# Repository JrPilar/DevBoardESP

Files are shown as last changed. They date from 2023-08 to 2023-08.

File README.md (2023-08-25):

# DevBoardESP
Dev Board based on ESP32-S3-WROOM2 chip to controll equatorial mount for telescope.  
Project made in KiCad6, for future printing. Board is architectured for future versions of ArduinoEQ, which will include autofocus motor, onboard RTC, GOTO etc.
Board is powered by 12V, has an USB-C port for COM port and programable NeoPixel.

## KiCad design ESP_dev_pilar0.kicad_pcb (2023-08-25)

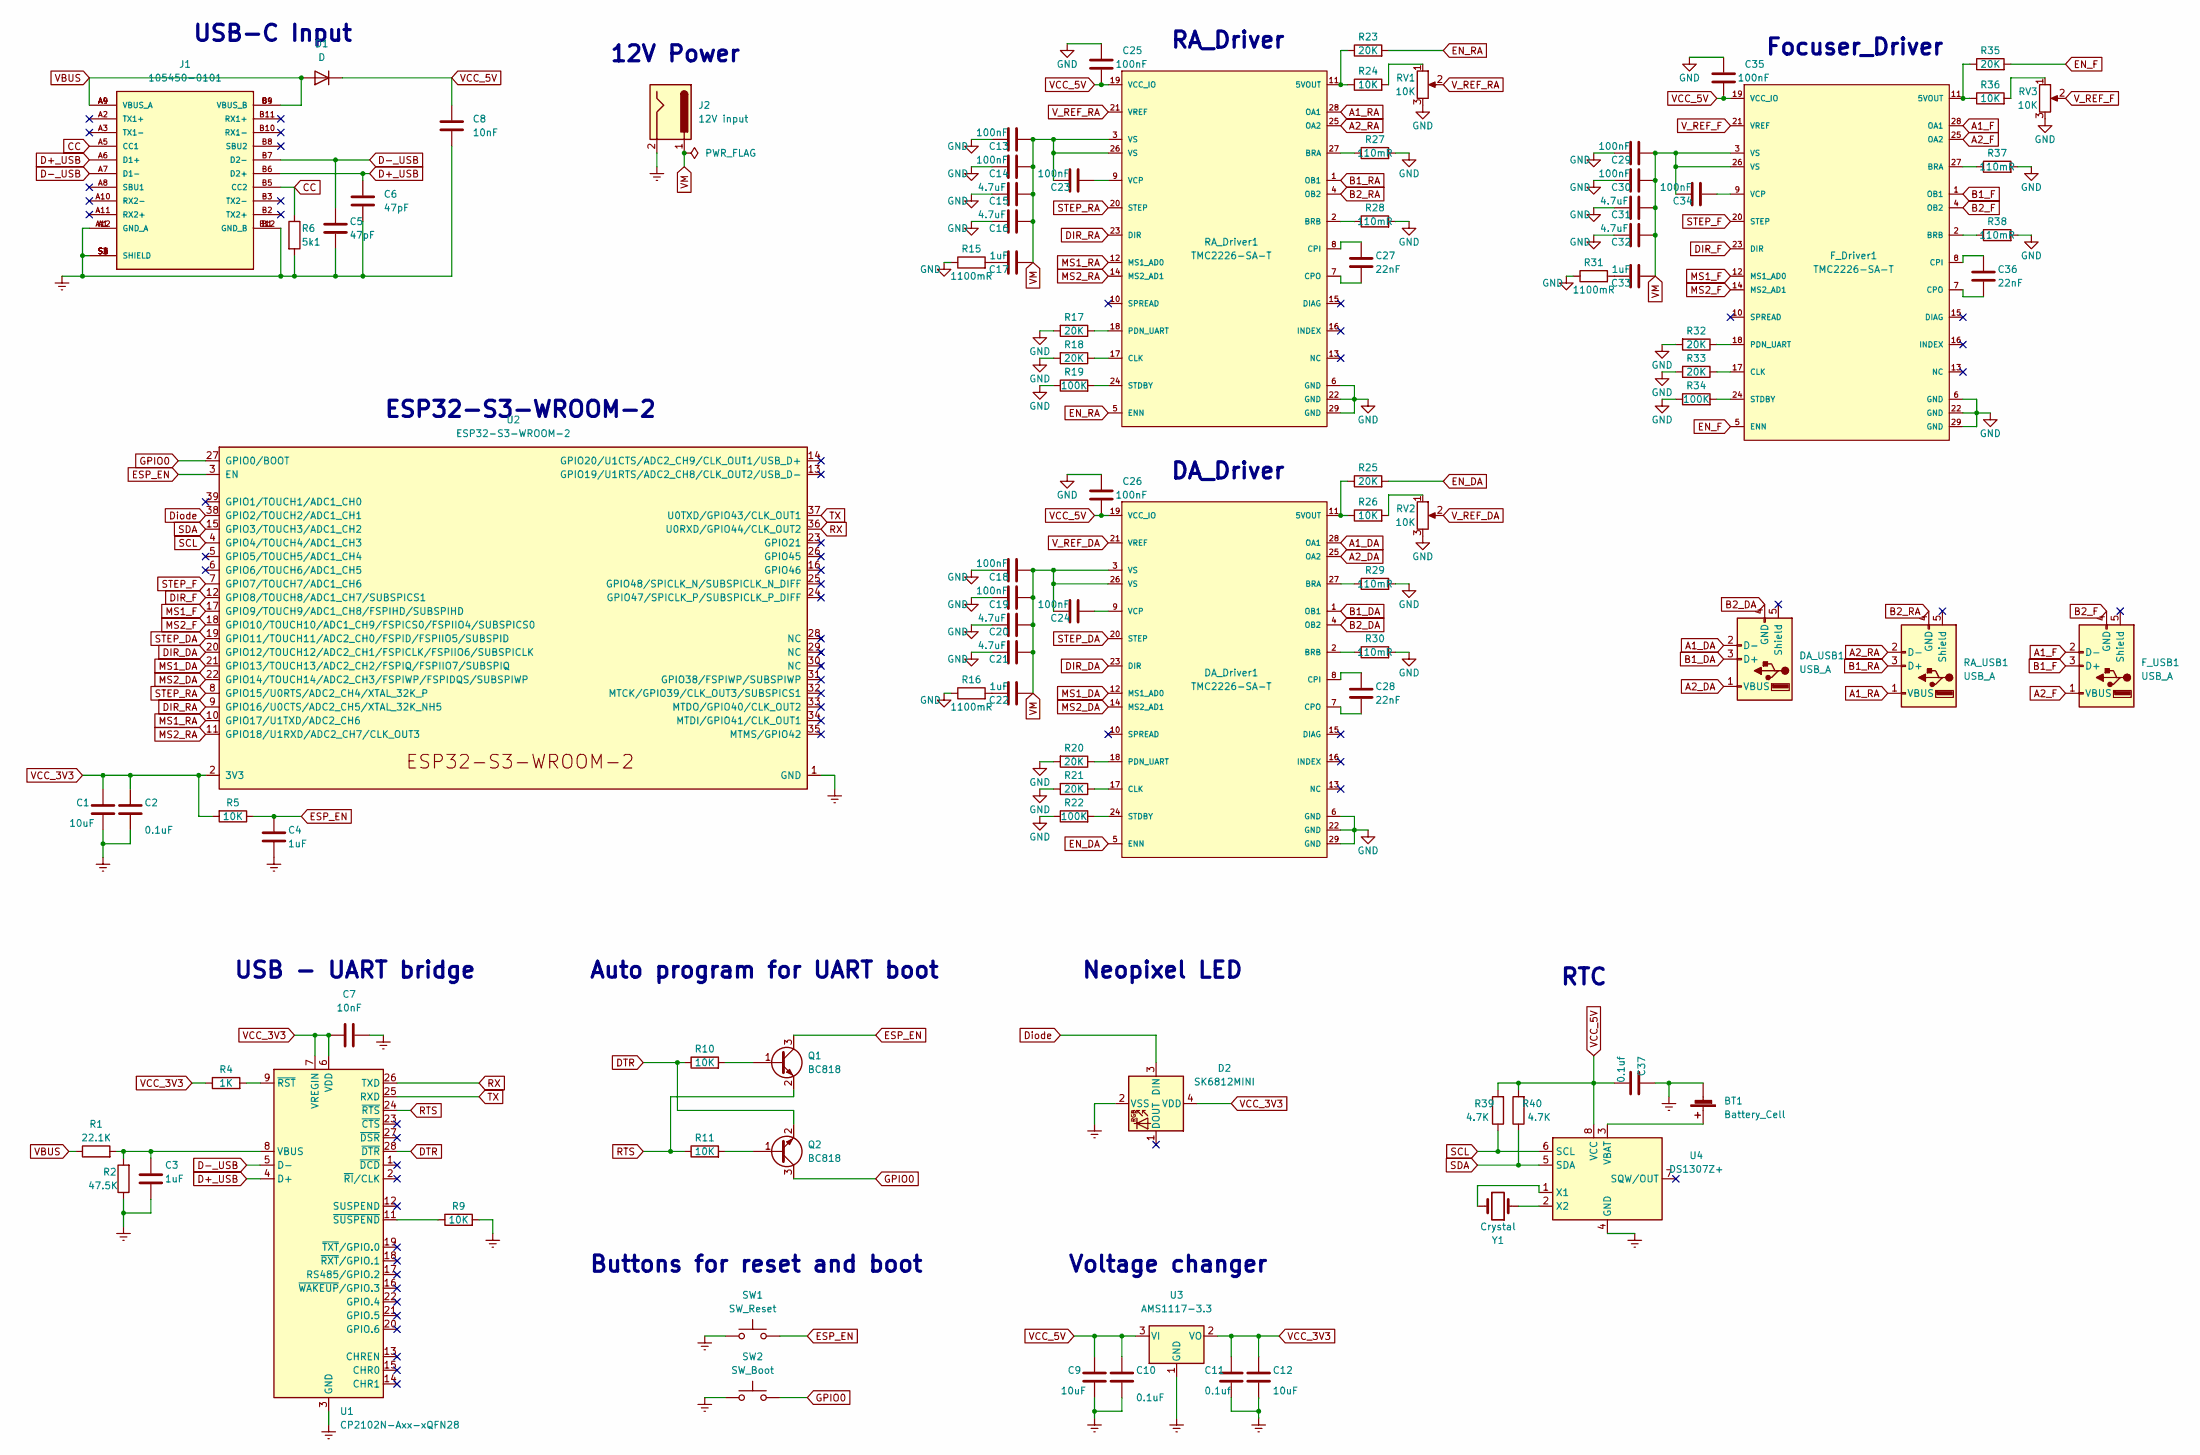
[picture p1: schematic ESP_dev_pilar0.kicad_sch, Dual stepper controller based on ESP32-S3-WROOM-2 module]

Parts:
BT1: Battery_Cell; BatteryHolder_Keystone_1057_1x2032
C1, C9, C12: 10uF; C_1210_3225Metric
C2, C10: 0.1uF; C_0603_1608Metric
C3, C4, C17, C22, C33: 1uF; C_0603_1608Metric
C5, C6: 47pF; C_0603_1608Metric
C7, C8: 10nF; C_0603_1608Metric
C11: 0.1uf; C_0603_1608Metric
C13, C14, C18, C19, C23, C24, C25, C26, C29, C30, C34, C35: 100nF; C_0603_1608Metric
C15, C16, C20, C21, C31, C32: 4.7uF; C_0603_1608Metric
C27, C28, C36: 22nF; C_0603_1608Metric
C37: 0.1uf; C_1210_3225Metric
D1: D; D_SOD-323
D2: SK6812MINI; LED_SK6812MINI_PLCC4_3.5x3.5mm_P1.75mm
DA_Driver1: TMC2226-SA-T; Trinamic-TMC2226-SA-T-IPC_B; mouser part number 700-TMC2226-SA-T; digikey description IC MTR DRV 4.75-29V HTSSOP28
DA_USB1: USB_A; USB_A_Molex_67643_Horizontal
F_Driver1: TMC2226-SA-T; Trinamic-TMC2226-SA-T-IPC_B; mouser part number 700-TMC2226-SA-T; digikey description IC MTR DRV 4.75-29V HTSSOP28
F_USB1: USB_A; USB_A_Molex_67643_Horizontal
J1: 105450-0101; USB_C_Receptacle_Molex_105450-0101; PARTREV A7
J2: 12V input; BarrelJack_Horizontal
Q1, Q2: BC818; SOT-23
R1: 22.1K; R_0603_1608Metric_Pad0.98x0.95mm_HandSolder
R2: 47.5K; R_0603_1608Metric_Pad0.98x0.95mm_HandSolder
R4: 1K; R_0603_1608Metric_Pad0.98x0.95mm_HandSolder
R5, R9, R10, R11: 10K; R_0603_1608Metric_Pad0.98x0.95mm_HandSolder
R6: 5k1; R_0603_1608Metric_Pad0.98x0.95mm_HandSolder
R15, R16, R31: 1100mR; R_1206_3216Metric_Pad1.30x1.75mm_HandSolder
R17, R18, R20, R21, R23, R25, R32, R33, R35: 20K; R_1206_3216Metric_Pad1.30x1.75mm_HandSolder
R19, R22, R34: 100K; R_1206_3216Metric_Pad1.30x1.75mm_HandSolder
R24, R26, R36: 10K; R_1206_3216Metric_Pad1.30x1.75mm_HandSolder
R27, R28, R29, R30, R37, R38: 110mR; R_0805_2012Metric_Pad1.20x1.40mm_HandSolder
R39, R40: 4.7K; R_0603_1608Metric_Pad0.98x0.95mm_HandSolder
RA_Driver1: TMC2226-SA-T; Trinamic-TMC2226-SA-T-IPC_B; mouser part number 700-TMC2226-SA-T; digikey description IC MTR DRV 4.75-29V HTSSOP28
RA_USB1: USB_A; USB_A_Molex_67643_Horizontal
RV1, RV2, RV3: 10K; Potentiometer_Bourns_TC33X_Vertical
SW1: SW_Reset; SW_Push_1P1T_NO_6x6mm_H9.5mm
SW2: SW_Boot; SW_Push_1P1T_NO_6x6mm_H9.5mm
U1: CP2102N-Axx-xQFN28; QFN-28-1EP_5x5mm_P0.5mm_EP3.35x3.35mm
U2: ESP32-S3-WROOM-2
U3: AMS1117-3.3; SOT-223-3_TabPin2
U4: DS1307Z+; SOIC-8_3.9x4.9mm_P1.27mm
Y1: Crystal; Crystal_DS26_D2.0mm_L6.0mm_Vertical

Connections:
A1_DA: DA_Driver1.28 (OA1), DA_USB1.2 (D-)
A1_F: F_Driver1.28 (OA1), F_USB1.2 (D-)
A1_RA: RA_Driver1.28 (OA1), RA_USB1.1 (VBUS)
A2_DA: DA_Driver1.25 (OA2), DA_USB1.1 (VBUS)
A2_F: F_Driver1.25 (OA2), F_USB1.1 (VBUS)
A2_RA: RA_Driver1.25 (OA2), RA_USB1.2 (D-)
B1_DA: DA_Driver1.1 (OB1), DA_USB1.3 (D+)
B1_F: F_Driver1.1 (OB1), F_USB1.3 (D+)
B1_RA: RA_Driver1.1 (OB1), RA_USB1.3 (D+)
B2_DA: DA_Driver1.4 (OB2), DA_USB1.4 (GND)
B2_F: F_Driver1.4 (OB2), F_USB1.4 (GND)
B2_RA: RA_Driver1.4 (OB2), RA_USB1.4 (GND)
CC: J1.A5 (CC1), J1.B5 (CC2), R6.1
D+_USB: C6.1, J1.A6 (D1+), J1.B6 (D2+), U1.4 (D+)
D-_USB: C5.2, J1.A7 (D1-), J1.B7 (D2-), U1.5 (D-)
DIR_DA: DA_Driver1.23 (DIR), U2.20 (GPIO12/TOUCH12/ADC2_CH1/FSPICLK/FSPIIO6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)
DIR_F: F_Driver1.23 (DIR), U2.12 (GPIO8/TOUCH8/ADC1_CH7/SUBSPICS1)
DIR_RA: RA_Driver1.23 (DIR), U2.9 (GPIO16/U0CTS/ADC2_CH5/XTAL_32K_NH5)
DTR: Q2.2 (E), R10.1, U1.28 (~DTR)
Diode: D2.3 (DIN), U2.38 (GPIO2/TOUCH2/ADC1_CH1)
EN_DA: DA_Driver1.5 (ENN), R25.2
EN_F: F_Driver1.5 (ENN), R35.2
EN_RA: R23.2, RA_Driver1.5 (ENN)
ESP_EN: C4.1, Q1.3 (C), R5.1, SW1.2, U2.3 (EN)
Earth: BT1.2 (-), C1.2, C2.2, C3.1, C4.2, C5.1, C6.2, C7.2, C8.2, C9.2, C10.2, C11.2, C12.2, C37.1, D2.2 (VSS), J1.A1 (GND_A), J1.A12 (GND_A), J1.B1 (GND_B), J1.B12 (GND_B), J1.S1 (SHIELD), J1.S2 (SHIELD), J1.S3 (SHIELD), J1.S4 (SHIELD), J2.2, R2.1, R6.2, R9.2, SW1.1, SW2.1, U1.3 (GND), U1.29 (GND), U2.1 (GND), U2.40 (GND), U2.41 (GND), U3.1 (GND), U4.4 (GND)
GND: C13.1, C14.1, C15.1, C16.1, C18.1, C19.1, C20.1, C21.1, C25.1, C26.1, C29.1, C30.1, C31.1, C32.1, C35.1, DA_Driver1.6 (GND), DA_Driver1.22 (GND), DA_Driver1.29 (GND), F_Driver1.6 (GND), F_Driver1.22 (GND), F_Driver1.29 (GND), R15.1, R16.1, R17.2, R18.2, R19.1, R20.2, R21.2, R22.1, R27.2, R28.2, R29.2, R30.2, R31.1, R32.2, R33.2, R34.1, R37.2, R38.2, RA_Driver1.6 (GND), RA_Driver1.22 (GND), RA_Driver1.29 (GND), RV1.3, RV2.3, RV3.3
GPIO0: Q2.3 (C), SW2.2, U2.27 (GPIO0/BOOT)
MS1_DA: DA_Driver1.12 (MS1_AD0), U2.21 (GPIO13/TOUCH13/ADC2_CH2/FSPIQ/FSPIIO7/S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)
MS1_F: F_Driver1.12 (MS1_AD0), U2.17 (GPIO9/TOUCH9/ADC1_CH8/FSPIHD/SUBSPIHD)
MS1_RA: RA_Driver1.12 (MS1_AD0), U2.10 (GPIO17/U1TXD/ADC2_CH6)
MS2_DA: DA_Driver1.14 (MS2_AD1), U2.22 (GPIO14/TOUCH14/ADC2_CH3/FSPIWP/FSPIDQS/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)
MS2_F: F_Driver1.14 (MS2_AD1), U2.18 (GPIO10/TOUCH10/ADC1_CH9/FSPICS0/FSPIIO4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)
MS2_RA: RA_Driver1.14 (MS2_AD1), U2.11 (GPIO18/U1RXD/ADC2_CH7/CLK_OUT3)
unnamed: BT1.1 (+), U4.3 (VBAT)
unnamed: C17.1, R15.2
unnamed: C22.1, R16.2
unnamed: C33.1, R31.2
unnamed: DA_Driver1.11 (5VOUT), R25.1, R26.1
unnamed: DA_Driver1.27 (BRA), R29.1
unnamed: DA_Driver1.2 (BRB), R30.1
unnamed: DA_Driver1.17 (CLK), R21.1
unnamed: C28.2, DA_Driver1.8 (CPI)
unnamed: C28.1, DA_Driver1.7 (CPO)
unnamed: DA_Driver1.18 (PDN_UART), R20.1
unnamed: DA_Driver1.24 (STDBY), R22.2
unnamed: C24.2, DA_Driver1.9 (VCP)
unnamed: F_Driver1.11 (5VOUT), R35.1, R36.1
unnamed: F_Driver1.27 (BRA), R37.1
unnamed: F_Driver1.2 (BRB), R38.1
unnamed: F_Driver1.17 (CLK), R33.1
unnamed: C36.2, F_Driver1.8 (CPI)
unnamed: C36.1, F_Driver1.7 (CPO)
unnamed: F_Driver1.18 (PDN_UART), R32.1
unnamed: F_Driver1.24 (STDBY), R34.2
unnamed: C34.2, F_Driver1.9 (VCP)
unnamed: Q1.1 (B), R10.2
unnamed: Q2.1 (B), R11.2
unnamed: R24.2, RV1.1
unnamed: R26.2, RV2.1
unnamed: R36.2, RV3.1
unnamed: R23.1, R24.1, RA_Driver1.11 (5VOUT)
unnamed: R27.1, RA_Driver1.27 (BRA)
unnamed: R28.1, RA_Driver1.2 (BRB)
unnamed: R18.1, RA_Driver1.17 (CLK)
unnamed: C27.2, RA_Driver1.8 (CPI)
unnamed: C27.1, RA_Driver1.7 (CPO)
unnamed: R17.1, RA_Driver1.18 (PDN_UART)
unnamed: R19.2, RA_Driver1.24 (STDBY)
unnamed: C23.2, RA_Driver1.9 (VCP)
unnamed: C3.2, R1.2, R2.2, U1.8 (VBUS)
unnamed: R4.2, U1.9 (~RST)
unnamed: R9.1, U1.11 (~SUSPEND)
unnamed: U4.1 (X1), Y1.2
unnamed: U4.2 (X2), Y1.1
RTS: Q1.2 (E), R11.1, U1.24 (~RTS)
RX: U1.26 (TXD), U2.36 (U0RXD/GPIO44/CLK_OUT2)
SCL: R39.1, U2.4 (GPIO4/TOUCH4/ADC1_CH3), U4.6 (SCL)
SDA: R40.1, U2.15 (GPIO3/TOUCH3/ADC1_CH2), U4.5 (SDA)
STEP_DA: DA_Driver1.20 (STEP), U2.19 (GPIO11/TOUCH11/ADC2_CH0/FSPID/FSPIIO5/S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)
STEP_F: F_Driver1.20 (STEP), U2.7 (GPIO7/TOUCH7/ADC1_CH6)
STEP_RA: RA_Driver1.20 (STEP), U2.8 (GPIO15/U0RTS/ADC2_CH4/XTAL_32K_P)
TX: U1.25 (RXD), U2.37 (U0TXD/GPIO43/CLK_OUT1)
VBUS: D1.2 (A), J1.A4 (VBUS_A), J1.A9 (VBUS_A), J1.B4 (VBUS_B), J1.B9 (VBUS_B), R1.1
VCC_3V3: C1.1, C2.1, C7.1, C11.1, C12.1, D2.4 (VDD), R4.1, R5.2, U1.6 (VDD), U1.7 (VREGIN), U2.2 (3V3), U3.2 (VO)
VCC_5V: C8.1, C9.1, C10.1, C25.2, C26.2, C35.2, C37.2, D1.1 (K), DA_Driver1.19 (VCC_IO), F_Driver1.19 (VCC_IO), R39.2, R40.2, RA_Driver1.19 (VCC_IO), U3.3 (VI), U4.8 (VCC)
VM: C13.2, C14.2, C15.2, C16.2, C17.2, C18.2, C19.2, C20.2, C21.2, C22.2, C23.1, C24.1, C29.2, C30.2, C31.2, C32.2, C33.2, C34.1, DA_Driver1.3 (VS), DA_Driver1.26 (VS), F_Driver1.3 (VS), F_Driver1.26 (VS), J2.1, RA_Driver1.3 (VS), RA_Driver1.26 (VS)
V_REF_DA: DA_Driver1.21 (VREF), RV2.2
V_REF_F: F_Driver1.21 (VREF), RV3.2
V_REF_RA: RA_Driver1.21 (VREF), RV1.2

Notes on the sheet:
RTC
Voltage changer
Auto program for UART boot
USB - UART bridge
Focuser_Driver
USB-C Input
Neopixel LED
RA_Driver
DA_Driver
Buttons for reset and boot
ESP32-S3-WROOM-2
12V Power

Board: 2 copper layers, 94 parts (0 on the bottom side), 89 nets, no tracks yet.
